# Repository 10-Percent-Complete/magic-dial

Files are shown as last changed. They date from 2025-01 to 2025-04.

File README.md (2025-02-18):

# Magic Dial

## Crates for custom PCB
| Name | Description | Crate |
| --- | --- | --- |
| HX711 | Strain Gauge IC | https://crates.io/crates/hx711 |
| GC9A01  | LCD Screen | https://crates.io/crates/gc9a01-rs |
| MT6701  | Hall Encoder | https://crates.io/crates/mt6701 |
| TMC6300 | Motor Driver | N/A |
| INA420  | Inline Phase Current | N/A |

## Info about devlepment board
| Name | URL |
| --- | --- |
| Sparkfun Board | https://docs.sparkfun.com/SparkFun_IoT_Brushless_Motor_Driver/introduction/ |
| TMC6300 Motor Driver | |
| TMAG5273 Hall Encoder | |
| INA420 Inline Phase Current | |
| MCP6021 Low-side Op Amp | |
| WS2812 RGB LED | https://crates.io/crates/ws2812-spi |

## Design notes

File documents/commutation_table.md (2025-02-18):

# Measurements
## 1 Phase High, 2 Low
| High Phase | 1 | 2 | 3 | 4 | 5 | 6 | 7 |
| --- | --- | --- | --- | --- | --- | --- | --- |
| V | 15.125 | 66.5 | 118.625  | 170.5 | 222.3125 | 273.25 | 323.9375 |
| U | 31.875 | 83.4375 | 135.5625 | 187.5 | 239.6875 | 290.75 | 340.875  |
| W | 49.625 | 101.375 | 152.875  | 204.875 | 256.5 | 307.3125 | 358.375  |

## 1 Phase High, 1 Low, 1 High Impedence
- 42 Unique States, Approx 8.57 degrees apart (360/42), 14 Slots, 8 Poles
- Cogging Steps = Slot Num / GCD(Slot Num, Pole Num) -> 14 / GCD(14, 8) -> 14 / 2 = 7

# Clockwise Commutation
| State | High Phase | Low Phase | Z Phase | 1 | 2 | 3 | 4 | 5 | 6 | 7 |
| ----- | --- | --- | --- | --- | --- | --- | --- | --- | --- | --- |
| 0 | W | U | V | 2.625 | 53.75  | 105.6875 | 157.3125 | 209.125  | 260.625  | 311.5625 |
| 1 | V | U | W | 10.75 | 62.25  | 114.125  | 166.125  | 218 | 269.0625 | 319.6875 |
| 2 | V | W | U | 19.25 | 70.875 | 122.8125 | 175.0625 | 226.75 | 277.875  | 328.1875 |
| 3 | U | W | V | 27.6875 | 79.125 | 131.125  | 183.5 | 235.6875 | 286.75 | 336.9125 |
| 4 | U | V | W | 36.1875 | 87.625 | 139.5625 | 191.875  | 243.8125 | 295 | 345.625  |
| 5 | W | V | U | 45.0625 | 96.625 | 148.1875 | 200.5 | 252.1875 | 303.1875 | 354.25 |

# Counter Clockwise Commutation
| State | High Phase | Low Phase | Z Phase | 1 | 2 | 3 | 4 | 5 | 6 | 7 |
| ----- | --- | --- | --- | --- | --- | --- | --- | --- | --- | --- |
| 0 | U | W | V | 2.625 | 53.75  | 105.6875 | 157.3125 | 209.125  | 260.625  | 311.5625 |
| 1 | U | V | W | 10.75 | 62.25  | 114.125  | 166.125  | 218 | 269.0625 | 319.6875 |
| 2 | W | V | U | 19.25 | 70.875 | 122.8125 | 175.0625 | 226.75 | 277.875  | 328.1875 |
| 3 | W | U | V | 27.6875 | 79.125 | 131.125  | 183.5 | 235.6875 | 286.75 | 336.9125 |
| 4 | V | U | W | 36.1875 | 87.625 | 139.5625 | 191.875  | 243.8125 | 295 | 345.625  |
| 5 | V | W | U | 45.0625 | 96.625 | 148.1875 | 200.5 | 252.1875 | 303.1875 | 354.25 |

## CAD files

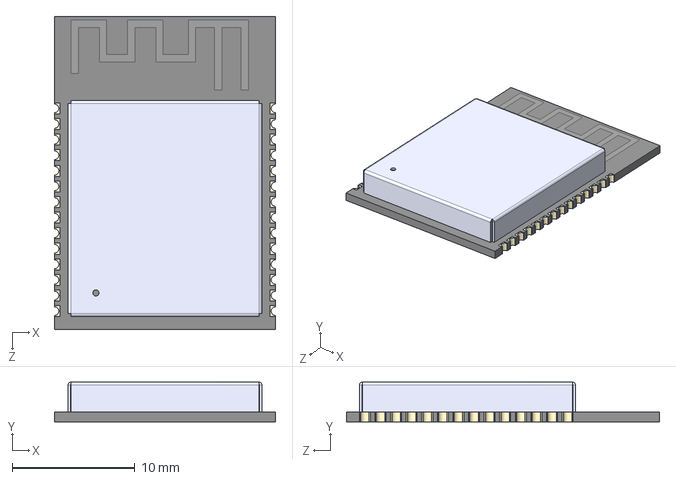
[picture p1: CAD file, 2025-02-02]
electrical hardware/EDA Models/ESP32_C6_WROOM_1_N8/ESP32-C6-WROOM-1-N8.step
18.0 x 3.25 x 25.5 mm

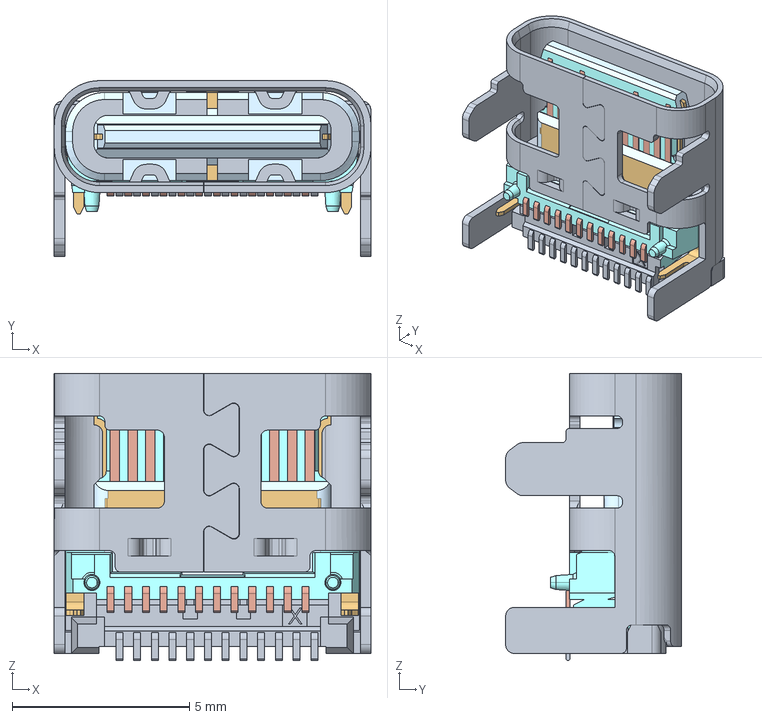
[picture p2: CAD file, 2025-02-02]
electrical hardware/EDA Models/GSB3C3133DS2HR/GSB3C3133DS2HR.step
8.95 x 4.96 x 8.10 mm

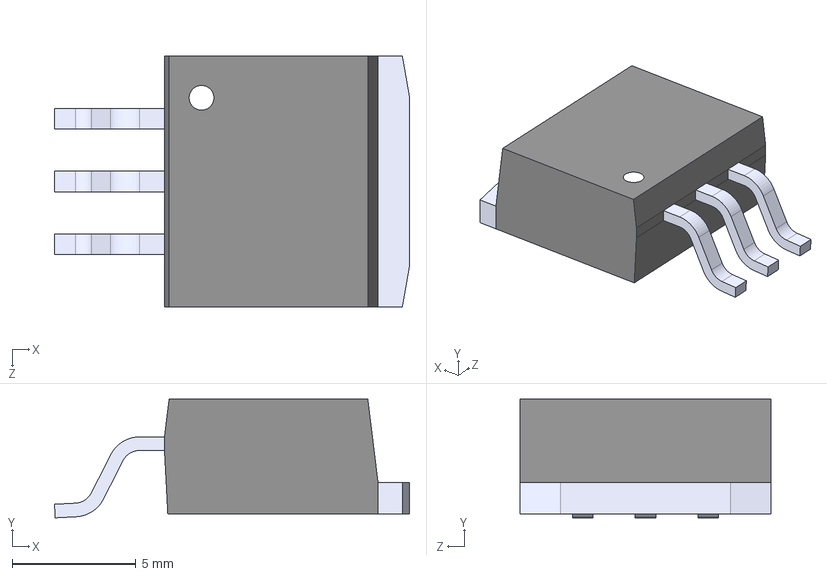
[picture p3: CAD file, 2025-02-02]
electrical hardware/EDA Models/LM1085ISX_5_0_NOPB/LM1085ISX-5.0_NOPB.step
14.4 x 4.80 x 10.2 mm

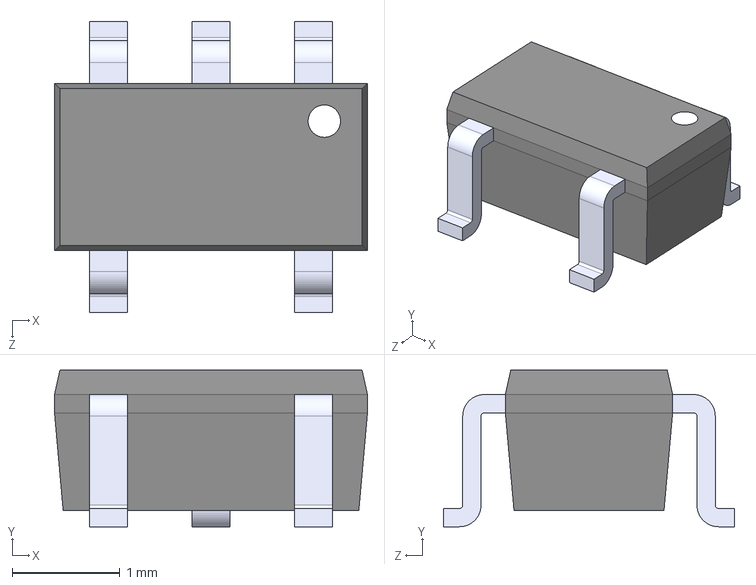
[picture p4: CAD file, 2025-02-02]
electrical hardware/EDA Models/MCP6021T_E_OT/MCP6021T-E_OT.step
2.90 x 1.45 x 2.70 mm

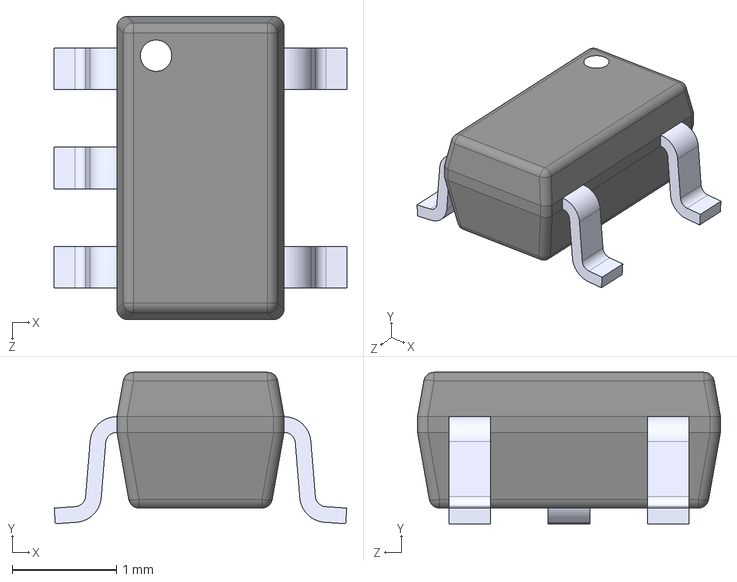
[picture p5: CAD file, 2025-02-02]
electrical hardware/EDA Models/TLV75733PDBVR/TLV75733PDBVR.step
2.80 x 1.45 x 2.90 mm

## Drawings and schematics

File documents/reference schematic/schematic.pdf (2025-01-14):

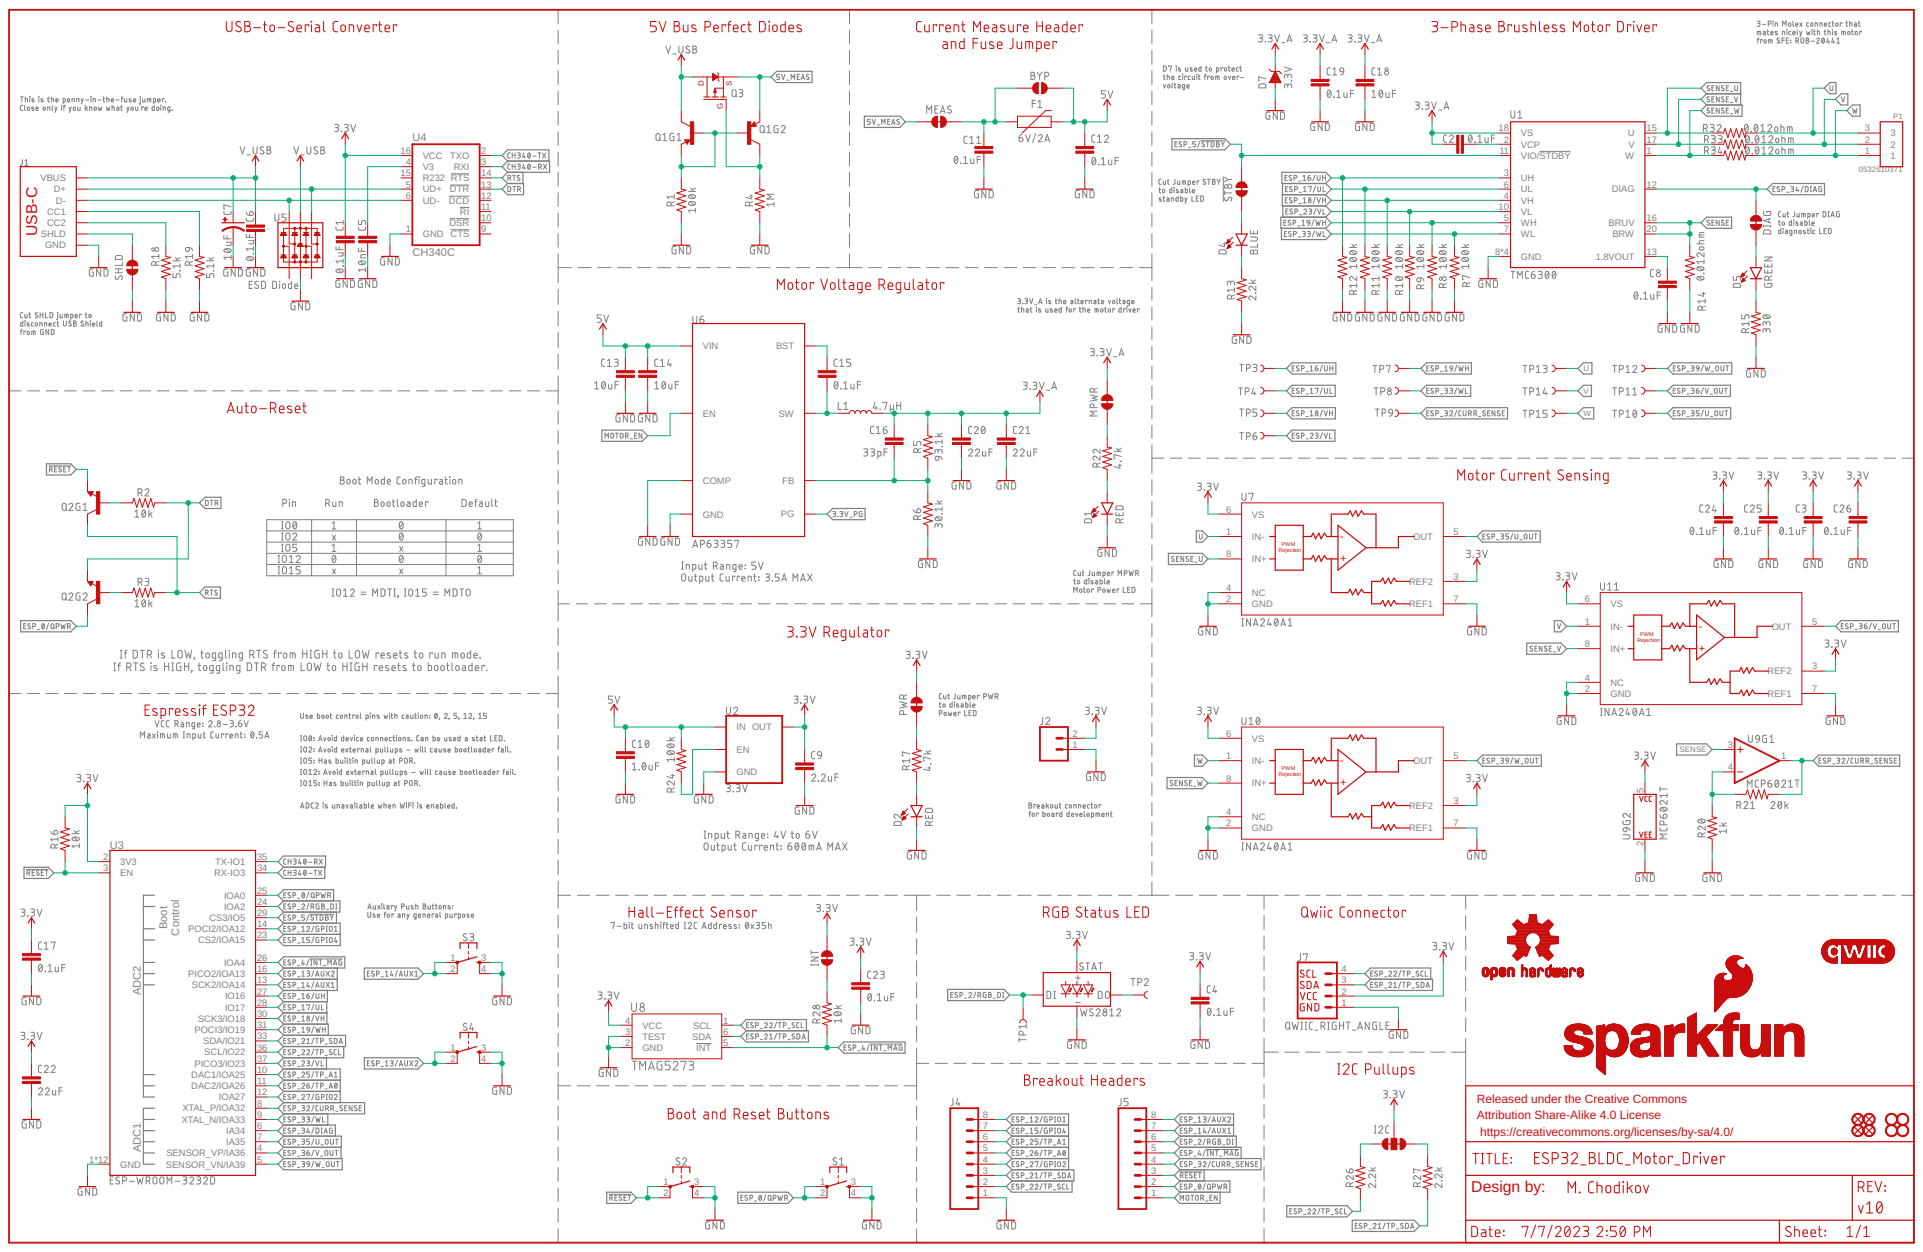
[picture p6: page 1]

ADC1 ADC2 Boot Control CH340C 0532610371 WH 5 W 1 GND 8*4 U 15 BRW 20 1.8VOUT 13 VIO/STDBY 11 VCP 2 UH 3 VH 4 DIAG 12 VS 18 UL 6 WL 7 BRUV 16 V 17 VL 10 GND VBUS CC1 D+D- CC2 SHLD 3V3 2 EN 3 SENSOR_VP/IA36 4 SENSOR_VN/IA39 5 IA34 6 IA35 7 XTAL_P/IOA32 8 XTAL_N/IOA33 9 DAC1/IOA25 10 DAC2/IOA26 11 IOA27 12 SCK2/IOA14 13 POCI2/IOA12 14 PICO2/IOA13 16 PICO3/IO23 37 SCL/IO22 36 TX-IO1 35 RX-IO3 34 SDA/IO21 33 POCI3/IO19 31 SCK3/IO18 30 CS3/IO5 29 IO17 28 IO16 27 IOA4 26 IOA0 25 IOA2 24 CS2/IOA15 23 GND 1*12U3 12345678 12345678 CTS 9 DCD 12 DSR 10 DTR 13 RI 11 RTS 14 GND 1 R232 15 RXI 3 TXO 2 UD+ 5 UD- 6 V3 4 VCC 16U4 1234 SCL 1 GND 2 TEST 3 VCC 4 INT 5 SDA 6 1 3 2 4 1 3 2 4 1 3 2 4 1 3 2 4 INGNDOUT EN 1 1 2 2 3 3 P1 VIN ENCOMP GND PGFB SWBST IN- 1 IN+ 8 REF1 7 REF2 3 NC 4 VS 6 GND 2 OUT 5 IN- 1 IN+ 8 REF1 7 REF2 3 NC 4 VS 6 GND 2 OUT 5 IN- 1 IN+ 8 REF1 7 REF2 3 NC 4 VS 6 GND 2 OUT 5 12 34 1 5 2 WVU SENSE Released under the Creative Commons Attribution Share-Alike 4.0 License https://creativecommons.org/licenses/by-sa/4.0/ Design by: USB-C DS G +- PWM Rejection +- PWM Rejection +- PWM Rejection

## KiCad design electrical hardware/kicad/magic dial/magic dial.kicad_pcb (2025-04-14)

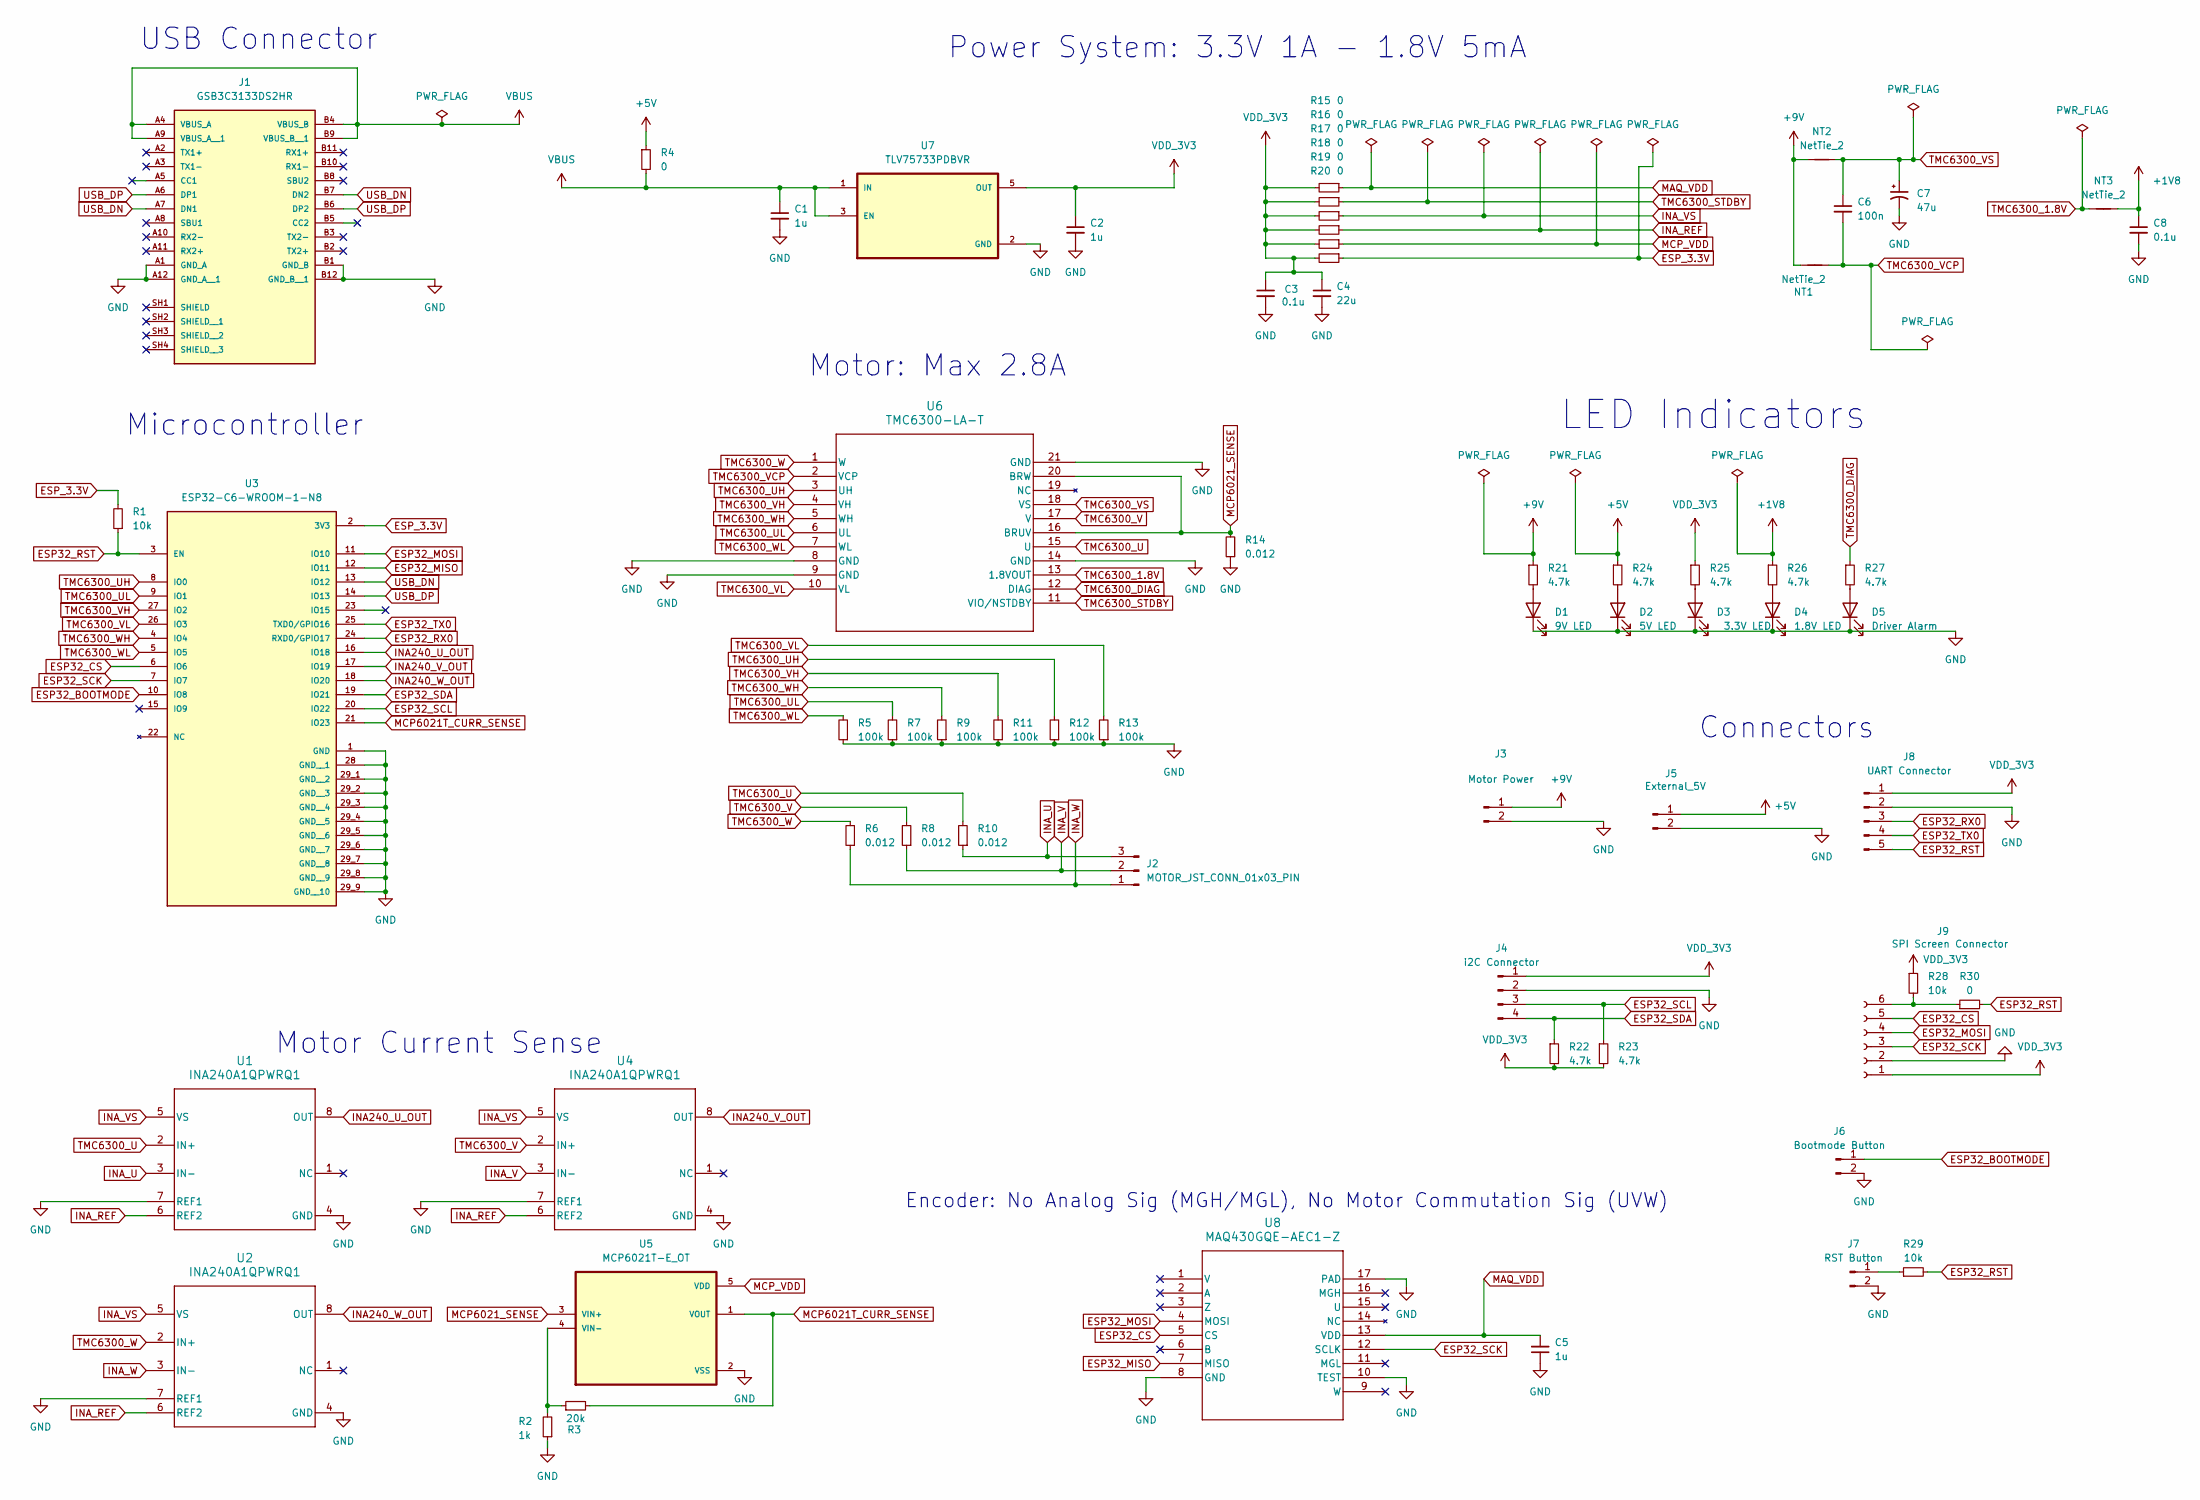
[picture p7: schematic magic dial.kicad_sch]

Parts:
C1, C2, C5: 1u; C_1206_3216Metric
C3, C8: 0.1u; C_1206_3216Metric
C4: 22u; C_1206_3216Metric
C6: 100n; C_1206_3216Metric
C7: 47u; C_1206_3216Metric
D1: 9V LED; LED_1206_3216Metric
D2: 5V LED; LED_1206_3216Metric
D3: 3.3V LED; LED_1206_3216Metric
D4: 1.8V LED; LED_1206_3216Metric
D5: Driver Alarm; LED_1206_3216Metric
J1: GSB3C3133DS2HR; AMPHENOL_GSB3C3133DS2HR; PARTREV AX1
J2: MOTOR_JST_CONN_01x03_PIN; JST_GH_SM03B-GHS-TB_1x03-1MP_P1.25mm_Horizontal
J3: Motor Power; PinHeader_1x02_P2.54mm_Vertical
J4: i2C Connector; PinHeader_1x04_P2.54mm_Vertical
J5: External_5V; PinHeader_1x02_P2.54mm_Vertical
J6: Bootmode Button; PinHeader_1x02_P2.54mm_Vertical
J7: RST Button; PinHeader_1x02_P2.54mm_Vertical
J8: UART Connector; PinHeader_1x05_P2.54mm_Vertical
J9: SPI Screen Connector; PinHeader_1x06_P2.54mm_Vertical
NT1, NT2, NT3: NetTie_2; NetTie-2_SMD_Pad0.5mm
R1, R28, R29: 10k; R_1206_3216Metric
R2: 1k; R_1206_3216Metric
R3: 20k; R_1206_3216Metric
R4, R15, R16, R17, R18, R19, R20, R30: 0; R_1206_3216Metric
R5, R7, R9, R11, R12, R13: 100k; R_1206_3216Metric
R6, R8, R10, R14: 0.012; R_1206_3216Metric
R21, R22, R23, R24, R25, R26, R27: 4.7k; R_1206_3216Metric
U1, U2, U4: INA240A1QPWRQ1; PW0008A_M
U3: ESP32-C6-WROOM-1-N8; XCVR_ESP32-C6-WROOM-1-N8; PARTREV 1.0
U5: MCP6021T-E_OT; SOT95P270X145-5N
U6: TMC6300-LA-T; 21-100586_K2033&plus_1C_ADI-M
U7: TLV75733PDBVR; SOT95P280X145-5N
U8: MAQ430GQE-AEC1-Z; QFN-16_MAQ430-M

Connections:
+1V8: C8.1, NT3.2, R26.1
+5V: J5.1, R4.1, R24.1
+9V: J3.1, NT1.1, NT2.1, R21.1
ESP32_BOOTMODE: J6.1, U3.10 (IO8)
ESP32_CS: J9.5, U3.6 (IO6), U8.5 (CS)
ESP32_MISO: U3.12 (IO11), U8.7 (MISO)
ESP32_MOSI: J9.4, U3.11 (IO10), U8.4 (MOSI)
ESP32_RST: J8.5, R1.1, R29.2, R30.2, U3.3 (EN)
ESP32_RX0: J8.3, U3.24 (RXD0/GPIO17)
ESP32_SCK: J9.3, U3.7 (IO7), U8.12 (SCLK)
ESP32_SCL: J4.3, R23.1, U3.20 (IO22)
ESP32_SDA: J4.4, R22.1, U3.19 (IO21)
ESP32_TX0: J8.4, U3.25 (TXD0/GPIO16)
ESP_3.3V: R1.2, R20.1, U3.2 (3V3)
GND: C1.2, C2.2, C3.2, C4.2, C5.1, C7.2, C8.2, D1.1 (K), D2.1 (K), D3.1 (K), D4.1 (K), D5.1 (K), J1.A1 (GND_A), J1.A12 (GND_A__1), J1.B1 (GND_B), J1.B12 (GND_B__1), J3.2, J4.2, J5.2, J6.2, J7.2, J8.2, J9.2, R2.1, R5.1, R7.1, R9.1, R11.1, R12.1, R13.1, R14.1, U1.4 (GND), U1.7 (REF1), U2.4 (GND), U2.7 (REF1), U3.1 (GND), U3.28 (GND__1), U3.29_1 (GND__2), U3.29_2 (GND__3), U3.29_3 (GND__4), U3.29_4 (GND__5), U3.29_5 (GND__6), U3.29_6 (GND__7), U3.29_7 (GND__8), U3.29_8 (GND__9), U3.29_9 (GND__10), U4.4 (GND), U4.7 (REF1), U5.2 (VSS), U6.8 (GND), U6.9 (GND), U6.14 (GND), U6.21 (GND), U7.2 (GND), U8.8 (GND), U8.10 (TEST), U8.17 (PAD)
INA240_U_OUT: U1.8 (OUT), U3.16 (IO18)
INA240_V_OUT: U3.17 (IO19), U4.8 (OUT)
INA240_W_OUT: U2.8 (OUT), U3.18 (IO20)
INA_REF: R18.1, U1.6 (REF2), U2.6 (REF2), U4.6 (REF2)
INA_U: J2.3, R10.1, U1.3 (IN-)
INA_V: J2.2, R8.1, U4.3 (IN-)
INA_VS: R17.1, U1.5 (VS), U2.5 (VS), U4.5 (VS)
INA_W: J2.1, R6.1, U2.3 (IN-)
MAQ_VDD: C5.2, R15.1, U8.13 (VDD)
MCP6021T_CURR_SENSE: R3.2, U3.21 (IO23), U5.1 (VOUT)
MCP6021_SENSE: R14.2, U5.3 (VIN+), U6.16 (BRUV), U6.20 (BRW)
MCP_VDD: R19.1, U5.5 (VDD)
unnamed: D1.2 (A), R21.2
unnamed: D2.2 (A), R24.2
unnamed: D3.2 (A), R25.2
unnamed: D4.2 (A), R26.2
unnamed: D5.2 (A), R27.2
unnamed: J7.1, R29.1
unnamed: J9.6, R28.2, R30.1
unnamed: R2.2, R3.1, U5.4 (VIN-)
TMC6300_1.8V: NT3.1, U6.13 (1.8VOUT)
TMC6300_DIAG: R27.1, U6.12 (DIAG)
TMC6300_STDBY: R16.1, U6.11 (VIO/NSTDBY)
TMC6300_U: R10.2, U1.2 (IN+), U6.15 (U)
TMC6300_UH: R12.2, U3.8 (IO0), U6.3 (UH)
TMC6300_UL: R7.2, U3.9 (IO1), U6.6 (UL)
TMC6300_V: R8.2, U4.2 (IN+), U6.17 (V)
TMC6300_VCP: C6.2, NT1.2, U6.2 (VCP)
TMC6300_VH: R11.2, U3.27 (IO2), U6.4 (VH)
TMC6300_VL: R13.2, U3.26 (IO3), U6.10 (VL)
TMC6300_VS: C6.1, C7.1, NT2.2, U6.18 (VS)
TMC6300_W: R6.2, U2.2 (IN+), U6.1 (W)
TMC6300_WH: R9.2, U3.4 (IO4), U6.5 (WH)
TMC6300_WL: R5.2, U3.5 (IO5), U6.7 (WL)
USB_DN: J1.A7 (DN1), J1.B7 (DN2), U3.13 (IO12)
USB_DP: J1.A6 (DP1), J1.B6 (DP2), U3.14 (IO13)
VBUS: C1.1, J1.A4 (VBUS_A), J1.A9 (VBUS_A__1), J1.B4 (VBUS_B), J1.B9 (VBUS_B__1), R4.2, U7.1 (IN), U7.3 (EN)
VDD_3V3: C2.1, C3.1, C4.1, J4.1, J8.1, J9.1, R15.2, R16.2, R17.2, R18.2, R19.2, R20.2, R22.2, R23.2, R25.1, R28.1, U7.5 (OUT)

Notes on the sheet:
Microcontroller
Motor: Max 2.8A
Connectors
USB Connector
Motor Current Sense
LED Indicators
Power System: 3.3V 1A - 1.8V 5mA
Encoder: No Analog Sig (MGH/MGL), No Motor Commutation Sig (UVW)

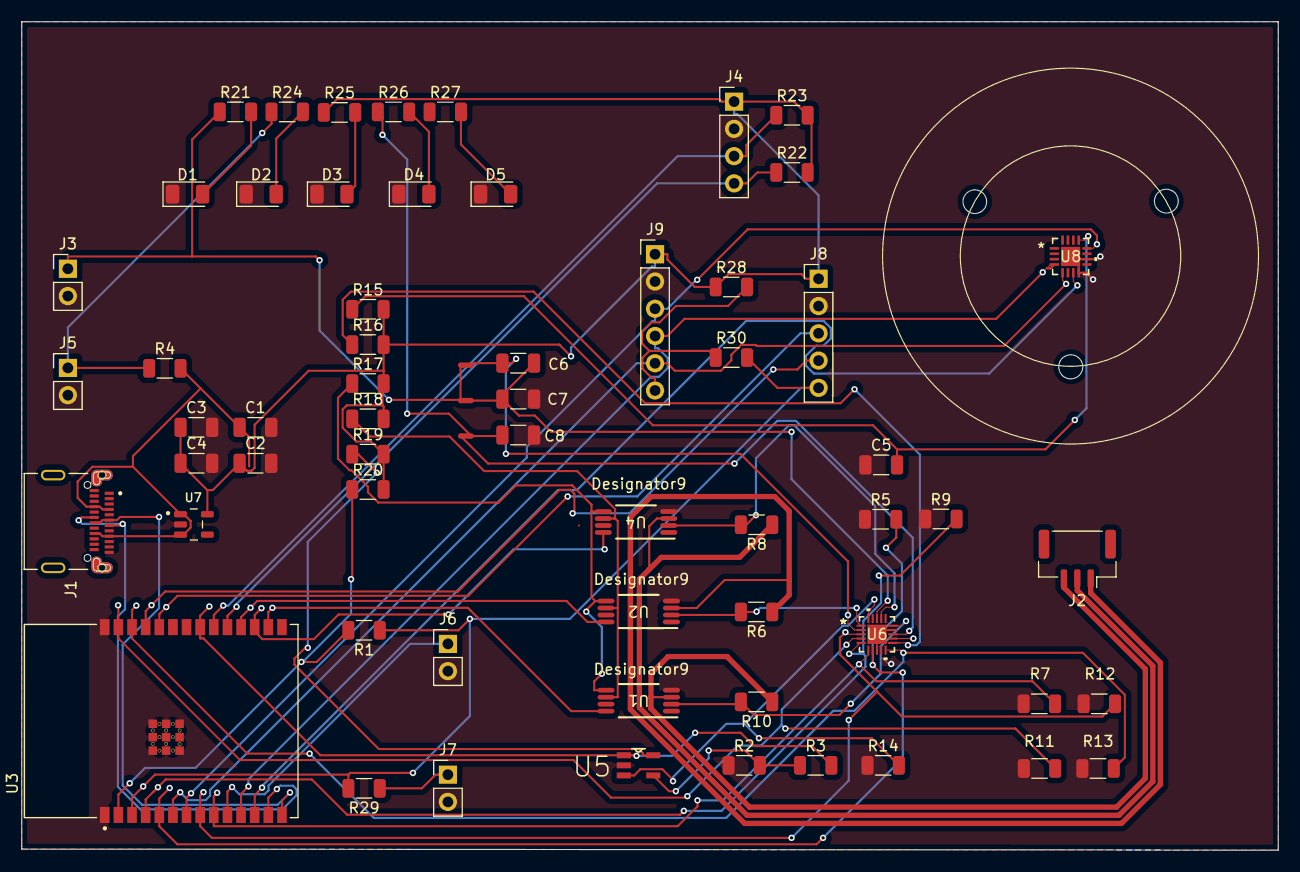
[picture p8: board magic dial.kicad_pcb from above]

Board: 2 copper layers, 117.1 x 77.2 mm, 63 parts (0 on the bottom side), 53 nets.

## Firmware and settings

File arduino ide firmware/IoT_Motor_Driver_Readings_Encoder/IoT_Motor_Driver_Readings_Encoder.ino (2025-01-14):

/**************************************************************
  Example: Position Hold (Resistance) with SparkFun IoT Brushless
           Motor Driver (ESP32 + TMC6300), TMAG5273 Hall Sensor,
           SimpleFOC, 2 Buttons, WS2812, and optional TFT display.

  Requirements/Assumptions:
  - We have a TMAG5273 that can give us an approximate angle of a magnet.
  - We do a simple P-control in user code to hold a target angle,
    resisting external rotation.

  Disclaimer:
  - This is a reference design. Adapt pin assignments, sensor reading,
    and motor control details to your specific hardware setup.
**************************************************************/

#include <Arduino.h>
#include <Wire.h>

// SimpleFOC
#include <SimpleFOC.h>  

// TMAG5273 Library (SparkFun)
#include <SparkFun_TMAG5273_Arduino_Library.h>
#include <SparkFun_TMAG5273_Arduino_Library_Defs.h>

// TFT_eSPI (optional for 240×240 GC9A01)
#include <TFT_eSPI.h>

// WS2812 LED
#include <Adafruit_NeoPixel.h>

// ----------------------------------------------------------------------------
// Pin Definitions (UPDATE to your actual wiring!)
// ----------------------------------------------------------------------------
// For TMC6300 6-PWM control (example pins from your working demo):
static const int PWM_AH = 5;
static const int PWM_AL = 6;
static const int PWM_BH = 9;
static const int PWM_BL = 10;
static const int PWM_CH = 3;
static const int PWM_CL = 11;

// Buttons
static const int BUTTON_MODE_PIN  = 13;
static const int BUTTON_VALUE_PIN = 14;

// WS2812 LED
static const int WS2812_PIN      = 2;
static const int WS2812_NUM_LEDS = 1;

// (Optional) TFT SPI pins if needed: 
//   SCK=18, MISO=19, MOSI=23, CS=5
//   => configured in User_Setup.h for TFT_eSPI

// ----------------------------------------------------------------------------
// Global Objects
// ----------------------------------------------------------------------------
BLDCMotor motor(7);  // 7 pole pairs example
BLDCDriver6PWM driver(PWM_AH, PWM_AL, PWM_BH, PWM_BL, PWM_CH, PWM_CL);

TMAG5273 tmag;       // Hall sensor object
TFT_eSPI tft = TFT_eSPI();  
Adafruit_NeoPixel strip(WS2812_NUM_LEDS, WS2812_PIN, NEO_GRB + NEO_KHZ800);

// Commander for debugging or user commands (optional)
Commander command = Commander(Serial);
// Commander callbacks (optional)
void doTarget(char* cmd) { command.scalar(&motor.target, cmd); }
void doLimit(char* cmd)  { command.scalar(&motor.voltage_limit, cmd); }

// ----------------------------------------------------------------------------
// Global Variables
// ----------------------------------------------------------------------------
// For demonstration, we do simple "P-control" around a targetAngle
bool holdEnabled   = true;   // if true, motor holds position
float targetAngle  = 0.0;    // in radians
float measuredAngle= 0.0;    // sensor reading in radians
float pGain        = 10.0;   // proportional gain for "resist"

bool lastButtonModeState  = HIGH;
bool lastButtonValueState = HIGH;

// ----------------------------------------------------------------------------
// 1) Setup Functions
// ----------------------------------------------------------------------------

void setupButtons() {
  pinMode(BUTTON_MODE_PIN,  INPUT_PULLUP);
  pinMode(BUTTON_VALUE_PIN, INPUT_PULLUP);
}

void setupWS2812() {
  strip.begin();
  strip.show(); // all off
}

void setupTFT() {
  tft.init();
  tft.setRotation(0);
  tft.fillScreen(TFT_BLACK);
  tft.setTextColor(TFT_WHITE, TFT_BLACK);
  tft.setTextSize(2);
}

void setupTMAG5273() {
  // Start I2C on pins SDA=21, SCL=22
  Wire.begin(21, 22); 
  delay(100);

  // If your library expects tmag.begin(Wire) or tmag.begin(address, Wire):
  if (!tmag.begin(Wire)) {
    Serial.println("TMAG5273 not detected!");
  } else {
    Serial.println("TMAG5273 detected.");
  }
}

void setupMotor() {
  // Driver config
  driver.voltage_power_supply = 3.3;  // 3.3V logic/power
  driver.voltage_limit        = 3.0;  // limit
  driver.pwm_frequency        = 32000;
  driver.init();
  motor.linkDriver(&driver);

  // Motor config
  motor.voltage_limit = 3.0;  
  // We'll do manual P-control, so set controller to open-loop angle
  motor.controller = MotionControlType::angle_openloop;  
  motor.init();

  // (Optional) Commander setup
  Serial.begin(115200);
  command.add('T', doTarget,  "target angle");
  command.add('L', doLimit,   "voltage limit");
  Serial.println("Motor ready!");
}

// ----------------------------------------------------------------------------
// 2) Loop Functions
// ----------------------------------------------------------------------------

void readButtons() {
  bool modeState  = digitalRead(BUTTON_MODE_PIN);
  bool valueState = digitalRead(BUTTON_VALUE_PIN);

  // If Button_MODE is pressed, shift target angle by 45 degrees
  if (modeState == LOW && lastButtonModeState == HIGH) {
    targetAngle += (PI/4.0);
    if (targetAngle > TWO_PI) {
      targetAngle -= TWO_PI;
    }
    Serial.print("New targetAngle(deg): ");
    Serial.println(targetAngle * 180.0/PI);
  }

  // If Button_VALUE is pressed, toggle hold on/off
  if (valueState == LOW && lastButtonValueState == HIGH) {
    holdEnabled = !holdEnabled;
    Serial.print("HoldEnabled = ");
    Serial.println(holdEnabled ? "TRUE" : "FALSE");
  }

  lastButtonModeState  = modeState;
  lastButtonValueState = valueState;
}

// Example function to read angle from the TMAG5273
void readSensorAngle() {
  // For new SparkFun library:
  if (tmag.checkDataReady()) {
    tmag.readAllAngles(); 
    float angleDeg = tmag.getAngleDeg(); // 0..360
    // Convert degrees -> radians
    measuredAngle = angleDeg * (PI/180.0);
  }

  // If you have an older library, adapt to get X/Y or getAngle() differently.
}

// Simple "P-control" approach to hold the angle
// The motor is in open-loop angle mode, so we manually compute commandedAngle
void updateMotor() {
  if (!holdEnabled) {
    // If hold not enabled, do nothing or set motor to zero angle
    motor.move(0);
    return;
  }

  // 1) Compute angle error
  float angleError = targetAngle - measuredAngle;

  // Keep error in [-PI, +PI] for stability
  if (angleError > PI)  angleError -= TWO_PI;
  if (angleError < -PI) angleError += TWO_PI;

  // 2) Commanded angle = measuredAngle + P * error
  float commandedAngle = measuredAngle + (pGain * angleError);

  // 3) Move the motor to that commanded angle in open-loop
  motor.move(commandedAngle);
}

// Optional function to show info on TFT and/or WS2812
void updateDisplay() {
  // Clear screen
  tft.fillScreen(TFT_BLACK);
  tft.setCursor(0, 0);
  tft.println("Hold Position Demo");
  tft.print("Hold: "); tft.println(holdEnabled ? "ON" : "OFF");

  tft.print("Target(deg): ");
  tft.println(targetAngle * 180.0/PI, 1);

  tft.print("Measured(deg): ");
  tft.println(measuredAngle * 180.0/PI, 1);

  // WS2812 color feedback
  if (holdEnabled) {
    // Green if holding
    strip.setPixelColor(0, strip.Color(0, 255, 0));
  } else {
    // Red if not
    strip.setPixelColor(0, strip.Color(255, 0, 0));
  }
  strip.show();
}

// Optional function to handle serial Commander or debug prints
void updateCommander() {
  command.run();

  static unsigned long lastPrint = 0;
  if (millis() - lastPrint > 500) {
    lastPrint = millis();
    Serial.print("HoldEnabled= ");
    Serial.print(holdEnabled);
    Serial.print(" | Target(deg)= ");
    Serial.print(targetAngle * 180.0/PI);
    Serial.print(" | Measured(deg)= ");
    Serial.println(measuredAngle * 180.0/PI);
  }
}

// ----------------------------------------------------------------------------
// Arduino Setup / Loop
// ----------------------------------------------------------------------------

void setup() {
  setupButtons();
  setupWS2812();
  setupTFT();
  setupTMAG5273();
  setupMotor();
}

void loop() {
  // 1) Read user input
  readButtons();

  // 2) Read sensor
  readSensorAngle();

  // 3) Update motor (hold or float)
  updateMotor();

  // 4) Optional: update display / LED
  updateDisplay();

  // 5) Commander / debug
  updateCommander();

  delay(20); // basic refresh period
}

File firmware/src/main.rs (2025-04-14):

#![no_std]
#![no_main]

use core::f32::consts::PI;

use drivers::tmag5273::{
    AngleEnable, ConversionRate, CrcEn, HystersisThreshold, I2cGlitchFilter, I2cReadMode, LowMode,
    MagneticConfig, MagnitudeGainChannel, OpMode, SleepConfig, TempCoeff,
    ThresholdTriggerDirection, ThresholdXCount, Tmag5273, TriggerMode, XYRange, ZRange,
    DEFAULT_I2C_ADDR,
};

use esp_backtrace as _;
use esp_hal::{
    delay::Delay,
    gpio::{Input, Output},
    main,
    mcpwm::timer::Timer,
    rtc_cntl::Rtc,
    time::ExtU64,
    timer::{timg::TimerGroup, PeriodicTimer},
    uart::{self, Config as UartConfig, Uart},
    Config,
};

use control::Control;
use motor::Motor;
use nb::block;
use pwm::{PwmPhases, PERIOD};

mod adc;
mod control;
mod drivers;
mod i2c;
mod motor;
mod pwm;

#[main]
fn main() -> ! {
    /* Initialize esp32 hardware */
    let peripherals = esp_hal::init(Config::default());

    /* Initialize log functionality */
    esp_println::logger::init_logger_from_env();

    /* Create delay object to use for code delays */
    let delay: Delay = Delay::new();

    /* Apply labels for all used pins */
    /* Buttons */
    let gpio_13 = peripherals.GPIO13;
    let gpio_14 = peripherals.GPIO14;

    /* UART Pins */
    let (tx_pin, rx_pin) = (peripherals.GPIO1, peripherals.GPIO3);

    let mut serial = Uart::new(peripherals.UART0, UartConfig::default())
        .unwrap()
        .with_rx(rx_pin)
        .with_tx(tx_pin);

    /* Initialize i2c controller */
    let i2c = i2c::init(
        peripherals.I2C0,
        peripherals.GPIO21, /* SDA */
        peripherals.GPIO22, /* SCL */
    );

    /* Initialize adc module */
    let adc = adc::init(
        peripherals.ADC1,
        peripherals.GPIO35, /* U Current */
        peripherals.GPIO36, /* V Current */
        peripherals.GPIO39, /* W Current */
        peripherals.GPIO32, /* Motor Current */
    );

    /* Initialize pwm module */
    let mut pwm_phases = PwmPhases::new(
        peripherals.MCPWM0,
        peripherals.GPIO16, /* U H */
        peripherals.GPIO17, /* U L */
        peripherals.GPIO18, /* V H */
        peripherals.GPIO23, /* V L */
        peripherals.GPIO19, /* W H */
        peripherals.GPIO33, /* W L */
    );

    /* Initialize motor object */
    let motor = Motor::new(4, 0.0, 0.0, 0.0, 3.3, 4.0, 4.0, 2.0);

    /* Initialize buttons */
    let btn_13 = Input::new(gpio_13, esp_hal::gpio::Pull::Up);
    let btn_14 = Input::new(gpio_14, esp_hal::gpio::Pull::Up);

    /* Initialize hall effect sensor object */
    let mut magnetic_sensor = Tmag5273::new(i2c, DEFAULT_I2C_ADDR);

    // /* Attempt to initialize the following magnetic sensor settings:
    //  * Average conversion rate: 32x
    //  * Low noise mode
    //  * Continuous sample mode
    //  * Enable XY channels
    //  * Enable angle conversion channels XY
    //  **/
    magnetic_sensor
        .config_device_1(
            CrcEn::Off,
            TempCoeff::_0,
            ConversionRate::_32x,
            I2cReadMode::I2cRead3,
        )
        .unwrap();

    magnetic_sensor
        .config_device_2(
            HystersisThreshold::TwoComplement,
            LowMode::LowNoise,
            I2cGlitchFilter::On,
            TriggerMode::Default,
            OpMode::Continuous,
        )
        .unwrap();

    magnetic_sensor
        .config_sensor_1(MagneticConfig::EnableXYX, SleepConfig::Sleep1ms)
        .unwrap();

    magnetic_sensor
        .config_sensor_2(
            ThresholdXCount::One,
            ThresholdTriggerDirection::Below,
            MagnitudeGainChannel::One,
            AngleEnable::EnableXY,
            XYRange::Default,
            ZRange::Default,
        )
        .unwrap();

    /* Initialize motor controller */
    let mut controller = Control::new(
        pwm_phases,
        motor,
        magnetic_sensor,
        control::ControllerType::velocity_open_loop,
    );

    let mut target_angle = PI;

    let timg0 = TimerGroup::new(peripherals.TIMG0);
    let mut periodic = PeriodicTimer::new(timg0.timer0);
    periodic.start(1.millis()).unwrap();

    // let mut byte = [0u8; 1];

    loop {
        controller.exec(target_angle);
        // match periodic.wait() {
        //     Ok(()) => {
        //         controller.exec(target_velocity);
        //     }
        //     Err(nb::Error::WouldBlock) => {
        //         if btn_13.is_low() && target_velocity < (PERIOD as f32) {
        //             target_velocity += 1.0;
        //         } else if btn_14.is_low() && target_velocity > 0.0 {
        //             target_velocity -= 1.0;
        //         }
        //     }
        // }

        /* Print data serially */
        // info!(
        //     "State: {}, Angle: {}, Speed: {}",
        //     commutation_state as u8, angle, speed
        // );
        // serial.read_buffered_bytes(&mut byte).unwrap();
        // serial.write_bytes(&byte).unwrap();
    }
}

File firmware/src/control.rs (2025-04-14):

use core::f32;
use core::f32::consts::FRAC_PI_3;

use embedded_hal::pwm::SetDutyCycle;
use esp_hal::i2c::master::I2c;
use esp_hal::mcpwm::operator::DeadTimeCfg;
use esp_hal::time::{now, ExtU64};
use esp_hal::{sha, Blocking};
use libm::{fmodf, sinf};
use log::info;

use f32::consts::{FRAC_PI_6, PI};

use crate::motor::Motor;
use crate::pwm::{PwmPhases, PERIOD};
use crate::Tmag5273;

pub enum ControllerType {
    velocity_open_loop = 0x0,
    angle_open_loop = 0x1,
    velocity = 0x2,
    angle = 0x3,
    torque = 0x4,
}

pub struct Control<'a> {
    phases: PwmPhases<'a>,
    motor: Motor,
    position_sensor: Tmag5273<I2c<'static, Blocking>>,
    controller_type: ControllerType,
}

impl<'a> Control<'a> {
    pub fn new(
        phases: PwmPhases<'a>,
        motor: Motor,
        position_sensor: Tmag5273<I2c<'static, Blocking>>,
        controller_type: ControllerType,
    ) -> Self {
        Self {
            phases,
            motor,
            position_sensor,
            controller_type,
        }
    }
    pub fn exec(&mut self, target: f32) {
        const SQRT_3: f32 = 1.732050807568877293527446341505872367_f32;

        /* Get position */
        let angle = self.position_sensor.read_angle().unwrap();
        let rad_angle = angle * (PI / 180.0);
        let sector = (((6.0 * (rad_angle / (2.0 * PI))) as i8) % 6) + 1;

        let vector_a = SQRT_3 * sinf(sector as f32 * FRAC_PI_3 - target);
        let vector_b: f32 = SQRT_3 * sinf(target - (FRAC_PI_3 * (sector as f32 - 1.0)));
        let period_0: f32 = 1.0 - vector_a - vector_b;

        let mut phase_u: f32 = 0.0;
        let mut phase_v: f32 = 0.0;
        let mut phase_w: f32 = 0.0;

        match sector {
            1 => {
                phase_u = vector_a + vector_b + (period_0 / 2.0);
                phase_v = vector_b + (period_0 / 2.0);
                phase_w = period_0 / 2.0;
            }
            2 => {
                phase_u = vector_a + (period_0 / 2.0);
                phase_v = vector_a + vector_b + (period_0 / 2.0);
                phase_w = period_0 / 2.0;
            }
            3 => {
                phase_u = period_0 + 2.0;
                phase_v = vector_a + vector_b + (period_0 / 2.0);
                phase_w = vector_b + (period_0 / 2.0);
            }
            4 => {
                phase_u = period_0 / 2.0;
                phase_v = vector_a + (period_0 / 2.0);
                phase_w = vector_a + vector_b + (period_0 / 2.0);
            }
            5 => {
                phase_u = vector_b + (period_0 / 2.0);
                phase_v = period_0 / 2.0;
                phase_w = vector_a + vector_b + (period_0 / 2.0);
            }
            6 => {
                phase_u = vector_a + vector_b + (period_0 / 2.0);
                phase_v = period_0 / 2.0;
                phase_w = vector_b + (period_0 / 2.0);
            }
            /* Disable all pins */
            _ => {
                phase_u = 0.0;
                phase_v = 0.0;
                phase_w = 0.0;
            }
        }

        // self.phases.set_phase((phase_u) as u16, (phase_v) as u16, (phase_w) as u16);

        self.phases.u.set_timestamp_a((phase_u * PERIOD as f32) as u16);
        self.phases.v.set_timestamp_a((phase_v * PERIOD as f32) as u16);
        self.phases.w.set_timestamp_a((phase_w * PERIOD as f32) as u16);

        info!("Sector:{} U:{} V:{} W:{}", sector, phase_u, phase_v, phase_w);
    }
}

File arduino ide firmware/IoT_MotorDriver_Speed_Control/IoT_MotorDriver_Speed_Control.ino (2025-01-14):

/*******************************************************
 * Single-Sketch Example: SparkFun TMAG5273 + SimpleFOC
 * 
 * Demonstrates how to:
 *  - Include the SparkFun TMAG5273 library FIRST
 *  - Define a custom Sensor class referencing SFE_TMAG5273
 *  - Use that sensor in closed-loop angle control
 *******************************************************/

#include <Arduino.h>
#include <Wire.h>
#include <SimpleFOC.h>

// 1) Include SparkFun TMAG5273 libraries BEFORE defining your sensor class
#include <SparkFun_TMAG5273_Arduino_Library.h>
#include <SparkFun_TMAG5273_Arduino_Library_Defs.h>

// ---------------------------------------------------------------------
//  Custom Sensor Class
// ---------------------------------------------------------------------
class SparkFunTMAG5273Sensor : public Sensor {
public:
  // Pass a reference to SFE_TMAG5273
  SparkFunTMAG5273Sensor(SFE_TMAG5273 &tmagObj) : _tmag(tmagObj) {}

  void init() override { _initialized = true; }

  float getAngle() override {
    if (!_initialized) return 0.0f;
    // Example read from XY plane:
    float angleDeg = _tmag.getMagneticAngleXY();
    float angleRad = angleDeg * DEG_TO_RAD;
    // wrap angle in [0..2π)
    angleRad = fmod(angleRad, TWO_PI);
    if (angleRad < 0) angleRad += TWO_PI;
    return angleRad;
  }

  float getVelocity() override { return NOT_SET; }

private:
  SFE_TMAG5273 &_tmag;
  bool _initialized = false;
};

// ---------------------------------------------------------------------
//  Pin definitions
// ---------------------------------------------------------------------
#define UH_PIN 16
#define UL_PIN 17
#define VH_PIN 18
#define VL_PIN 23
#define WH_PIN 19
#define WL_PIN 33

// Current sense pins
#define CUR_SENSE_A 4
#define CUR_SENSE_B 5
#define CUR_SENSE_C 7
#define CUR_SENSE_TOTAL 8

// Buttons
#define BTN_ENABLE 13
#define BTN_SPEED  14

// ---------------------------------------------------------------------
//  Global objects
// ---------------------------------------------------------------------
BLDCMotor motor(7); // e.g. 7 pole pairs
BLDCDriver6PWM driver(UH_PIN, UL_PIN, VH_PIN, VL_PIN, WH_PIN, WL_PIN);
InlineCurrentSense current_sense(0.012f, 3.3f, CUR_SENSE_A, CUR_SENSE_B, CUR_SENSE_C);

SFE_TMAG5273 tmag;  // SparkFun

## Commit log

2025-01-14 Day 1
    Day 1
    Test Firmware and Reference material
2025-01-14 Added Encoder Code
    Added Encoder Code
2025-01-16 Created Rust blink rgb led for sparkfun board
2025-02-02 Major KiCad Update and EDA Models
    Major KiCad Update and EDA Models
    [ESP32-C6-WROOM-1-N8.step, GSB3C3133DS2HR.step, LM1085ISX-5.0_NOPB.step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]
2025-02-03 Added proof of concept rust code for reading hall effect axis registers
2025-02-03 Major Update: Added Power, and Motor to Schematics
    Major Update: Added Power, and Motor to Schematics
    [magic dial.kicad_sch]
2025-02-06 Created file structure for rust sensor drivers
2025-02-09 Setup driver structure for tmag encoder
2025-02-09 Added configure/read functions for magnetic sensor
2025-02-13 Added current sensor adc reading support
2025-02-18 Added open loop commutation control and added all configuration functions for tmag driver
2025-03-08 Organized file hiearchy through control/motor/pwm.rs modules. Hard coded 120 trapezoid open velocity
2025-03-20 PWM motor commutation setup
2025-04-14 Completed V1 Schematics, requires validation.
    Completed V1 Schematics, requires validation.
    [magic dial.kicad_sch]
2025-04-14 Completed Validation or Schematic. Removed Errors. Needs Footprint assignment
    [magic dial.kicad_sch]
2025-04-14 Assigned footprints for universal components. Need to do custom Components
    Assigned footprints for universal components. Need to do custom Components
    [magic dial.kicad_sch]
2025-04-14 Completed Initial Layout for PCB
    [magic dial.kicad_pcb, magic dial.kicad_sch]
2025-04-14 Auto Route Progress: Incomplete.
    Auto Route Progress: Incomplete.
    [magic dial.dsn, magic dial.kicad_pcb, magic dial.kicad_sch]
